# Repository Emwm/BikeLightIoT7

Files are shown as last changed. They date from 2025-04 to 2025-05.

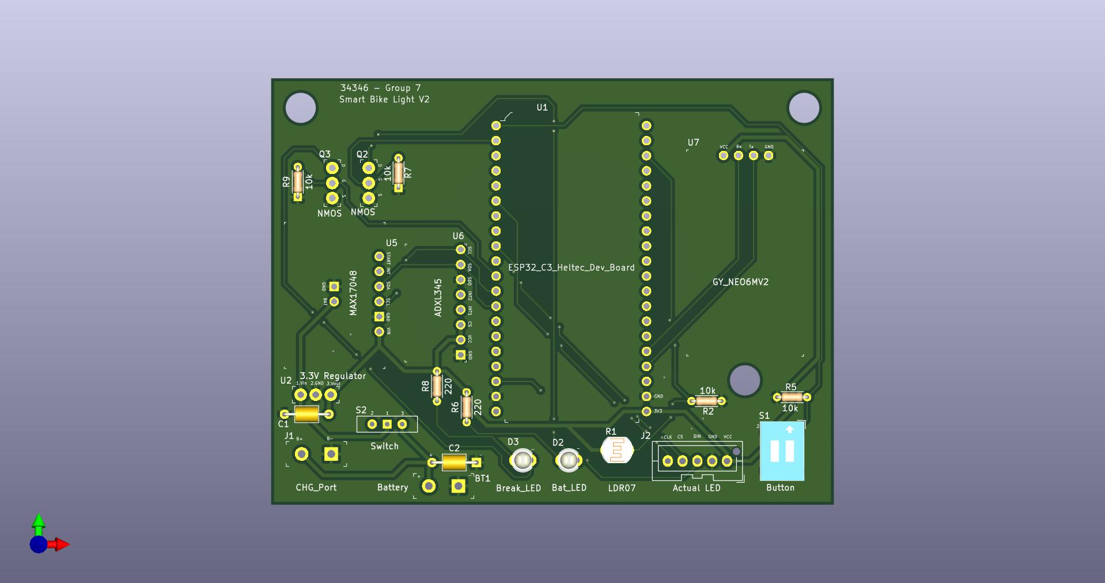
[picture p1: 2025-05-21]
Electronic Hardware/PCB Images/PCB_Rendered_Image.jpg

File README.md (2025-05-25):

# 🚲 ESP32 Smart Bike Tracker

An ESP32-based smart tracking and monitoring system for bicycles, combining GNSS (GPS) tracking, motion detection, power management, battery monitoring, and LoRa communication to create an intelligent, low-power system for bike security and telemetry.

---

## 📚 Table of Contents

- [Features](#-features)
- [Getting Started](#-getting-started)
- [Power Modes](#-power-modes)
- [GNSS (GPS) Handler](#-gnss-gps-handler)
- [Motion Detector](#-motion-detector)
- [Light Control](#-light-control)
- [LoRa Communication](#-lora-communication)
- [Battery Monitoring](#-battery-monitoring)
- [Inactivity Handling](#-inactivity-handling)
- [Main Loop Overview](#-main-loop-overview)
- [Modules Summary](#-modules-summary)
- [Contributing](#-contributing)
- [License](#-license)

---

## 📦 Features

- Real-time GPS tracking  
- LoRa communication to send bike data remotely  
- Motion detection using an accelerometer  
- Battery monitoring via MAX17048 fuel gauge  
- Smart power management with 3 modes: ACTIVE, PARK, SLEEP  
- Inactivity-based sleep transitions  
- Wake-up on button press or timer  
- Integrated button and light control  

---

## 🛠️ Getting Started

### ✅ Prerequisites

- PlatformIO or Arduino IDE  
- ESP32 board definitions installed  
- Required libraries:  
  - TinyGPS++  
  - Wire  
  - SPI  

### 🚀 Flashing the Firmware

```bash
git clone https://github.com/youruser/esp32-smart-bike-tracker.git
cd esp32-smart-bike-tracker
# Open with Arduino IDE or PlatformIO and upload to your ESP32
```

---

## 🔘 Button Handler

Manages button input from GPIO 33, used to:
- Wake up the system
- Trigger GPS updates
- Toggle power modes

### ⚙️ Configuration

| Constant | Description |
|---|---|
| `BUTTON_PIN_1` | GPIO pin for Button 1 (GPIO33) |

```cpp
#define BUTTON_PIN_1 33
```

### 📦 Variables

```cpp
extern volatile bool button1Pressed;
extern unsigned long lastActivityTime;
```

### 📋 API

| Function | Description |
|---|---|
| `setupButtons()` | Initializes GPIOs as `INPUT_PULLDOWN` |
| `checkButtonPresses()` | Resets flags, updates `lastActivityTime` |

---

## 🧠 Power Modes

System behavior varies by mode:

### 🟢 ACTIVE Mode
- Full GPS + LoRa operation
- Motion detection and lighting enabled
- Auto-exit on inactivity

### 🟡 PARK Mode
- Enters light sleep
- Periodic wake via RTC or button
- Ideal for short-term stationary periods

### 🔴 SLEEP Mode
- Enters deep sleep for max power saving
- Wake on button press only
- Best for long inactivity

---

## 🛰 GNSS (GPS) Handler

Handles GPS data using the TinyGPS++ library. Sends the location everytime the mode of the system changes.

### 📋 API

| Method | Description |
|---|---|
| `begin()` | Initializes GPS module |
| `update()` | Feeds serial data to TinyGPS++ |
| `isConnected()` | Checks for GPS fix (≥4 satellites) |
| `checkLocation()` | Returns `GPSPosition` with lat/lon |

### 📍 Example

This flag is used to update the location and send it.

```cpp
if (sendLocationFlag) {
    GPSPosition pos = gnss.checkLocation();
    // Use pos.latitude, pos.longitude
}
```

---

## 🕹️ Motion Detector

Detects bike movement using a 3-axis accelerometer (e.g. ADXL345).

### 📋 API

| Method | Description |
|---|---|
| `isMoving()` | Returns `true` if movement detected |
| `begin()` | Initializes the sensor |
| `MotionDetector(...)` | Constructor with I2C address and threshold |

```cpp
MotionDetector motion(0x53); // ADXL345 default I2C address
```

---

## 💡 Light Control

Uses an LDR + MAX7219 LED matrix to control lights.

### ⚙️ Configuration

| Item | Pin |
|---|---|
| `LDR_PIN` | Analog Input |
| `LED_LOW_BAT` | Digital Output |
| `DIN` | GPIO 14 |
| `CLK` | GPIO 13 |
| `CS` | GPIO 12 |

### 📋 API

| Function | Description |
|---|---|
| `setupLight()` | Initializes LED matrix |
| `controlLight()` | Enables/disables display based on LDR |
| `turnLightoff()` | Manually disables display |
| `manageBatteryWarning(float)`| Activates LED when battery < 25% |

---

## 📡 LoRaWAN Communication

Handles uplink/downlink communication via RN2483 LoRa module using OTAA.

### 🔧 ESP32 to RN2483 Wiring

| Function | ESP32 Pin |
|---|---|
| TX → RN  | GPIO 19 |
| RX ← RN  | GPIO 18 |
| RESET | GPIO 23 |

### 📋 API

| Function | Description |
|---|---|
| `init_lora()` | Initializes LoRaWAN + joins TTN |
| `send_lora(devMode, battery, lon, lat)` | Sends telemetry as CSV string |
| `recieve_lora()` | Reads JSON downlink and parses value|

### 📤 Uplink Format (CSV)

```text
1,3.85,12.34,56.78
```

### 📥 Downlink Format

TTN → JSON string in HEX:

```json
{"value": 2}
```

TTN Payload: `7b2276616c7565223a20327d`

Parsed into `int value = 2`.

---

## 🔋 Battery Monitoring

Powered by the MAX17048 fuel gauge.

```cpp
batterypercentage = battery.percent();
```

Low battery warning is triggered by:

```cpp
manageBatteryWarning(batterypercentage);
```

---

## ⏱️ Inactivity & Mode Handling

Automatically switches to `PARK` mode if idle for 60 seconds:

```cpp
if (millis() - lastActivityTime > 60000) {
    // Switch to PARK
}
```

Button interrupt handler toggles modes:

```cpp
void IRAM_ATTR handleInterrupt1();
```

Transitions:
- `ACTIVE → PARK`
- `PARK → SLEEP`

---

## 🔁 Main Loop Structure

```cpp
switch (getCurrentMode()) {
    case ACTIVE:
        // Motion + LoRa
        break;
    case PARK:
        // Light sleep
        break;
    case SLEEP:
        // Deep sleep
        break;
}
```

---

## 🛠 Modules Summary

| Module | Description |
| --- | --- |
| powerModes | Manages sleep states and wake sources  |
| GNSSHandler | Handles GPS via GNSS |
| MotionDetector | Reads accelerometer to detect movement |
| ESP32\_lora | Sends and receives data via LoRa |
| MAX17048 | Monitors battery charge level |
| buttonHandler  | Detects button presses |
| lightControl | Manages LED or light control |

## Authors

Group 7 in the DTU course 34346 Networking technologies and application development for IoT

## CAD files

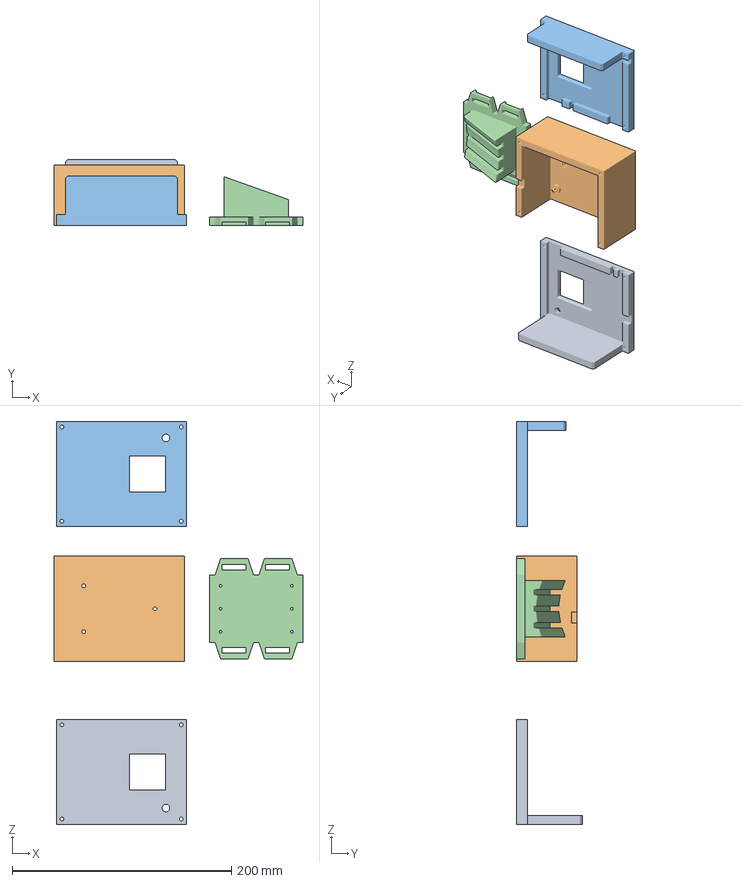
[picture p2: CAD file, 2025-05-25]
CAD Files/BikeLightCase full.3mf
227.0 x 60.0 x 368.0 mm

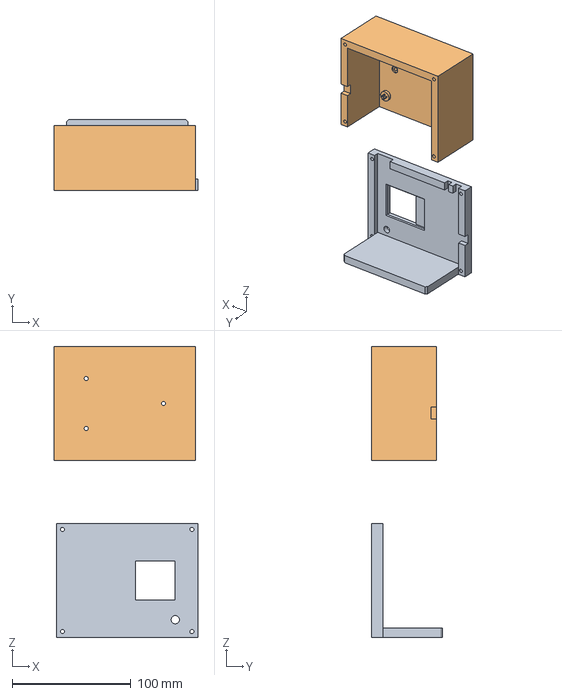
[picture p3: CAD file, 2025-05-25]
CAD Files/BikeLightCase v6.3mf
121.0 x 60.0 x 245.0 mm

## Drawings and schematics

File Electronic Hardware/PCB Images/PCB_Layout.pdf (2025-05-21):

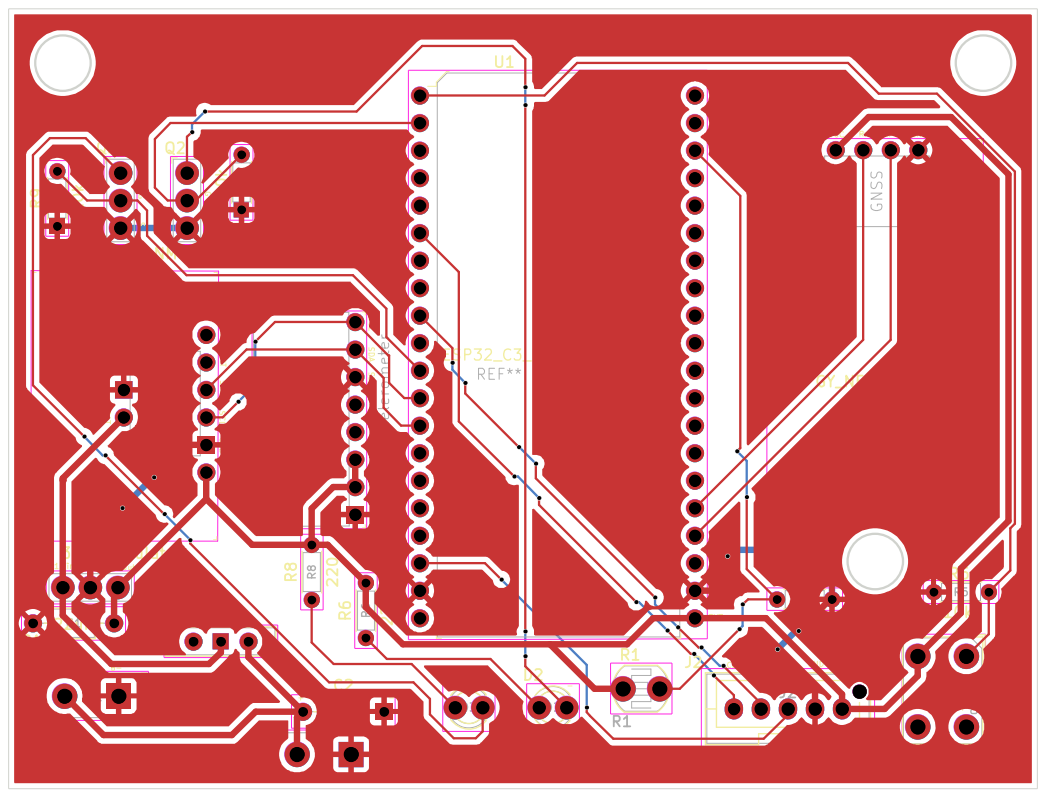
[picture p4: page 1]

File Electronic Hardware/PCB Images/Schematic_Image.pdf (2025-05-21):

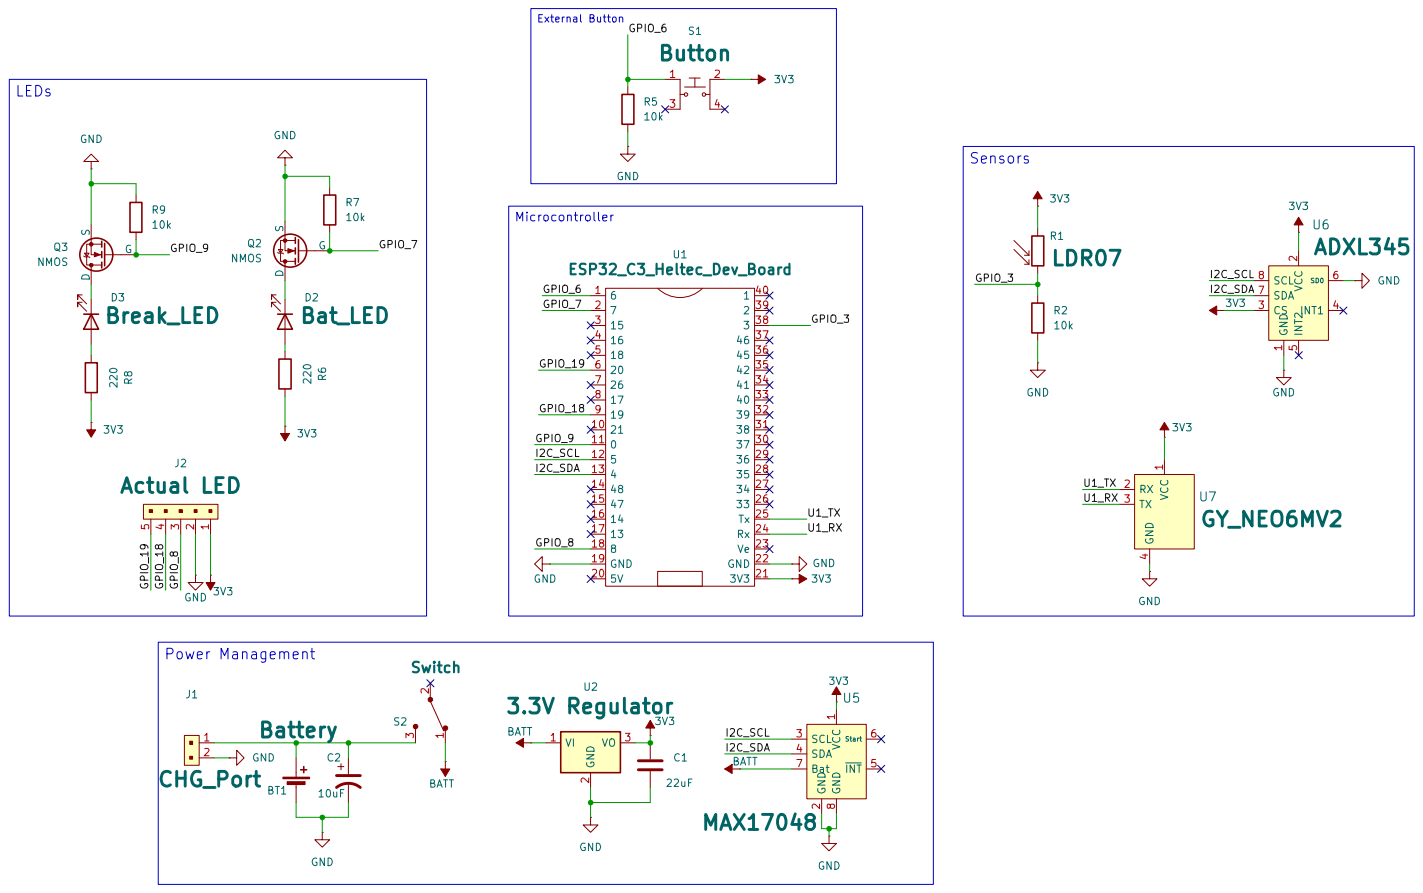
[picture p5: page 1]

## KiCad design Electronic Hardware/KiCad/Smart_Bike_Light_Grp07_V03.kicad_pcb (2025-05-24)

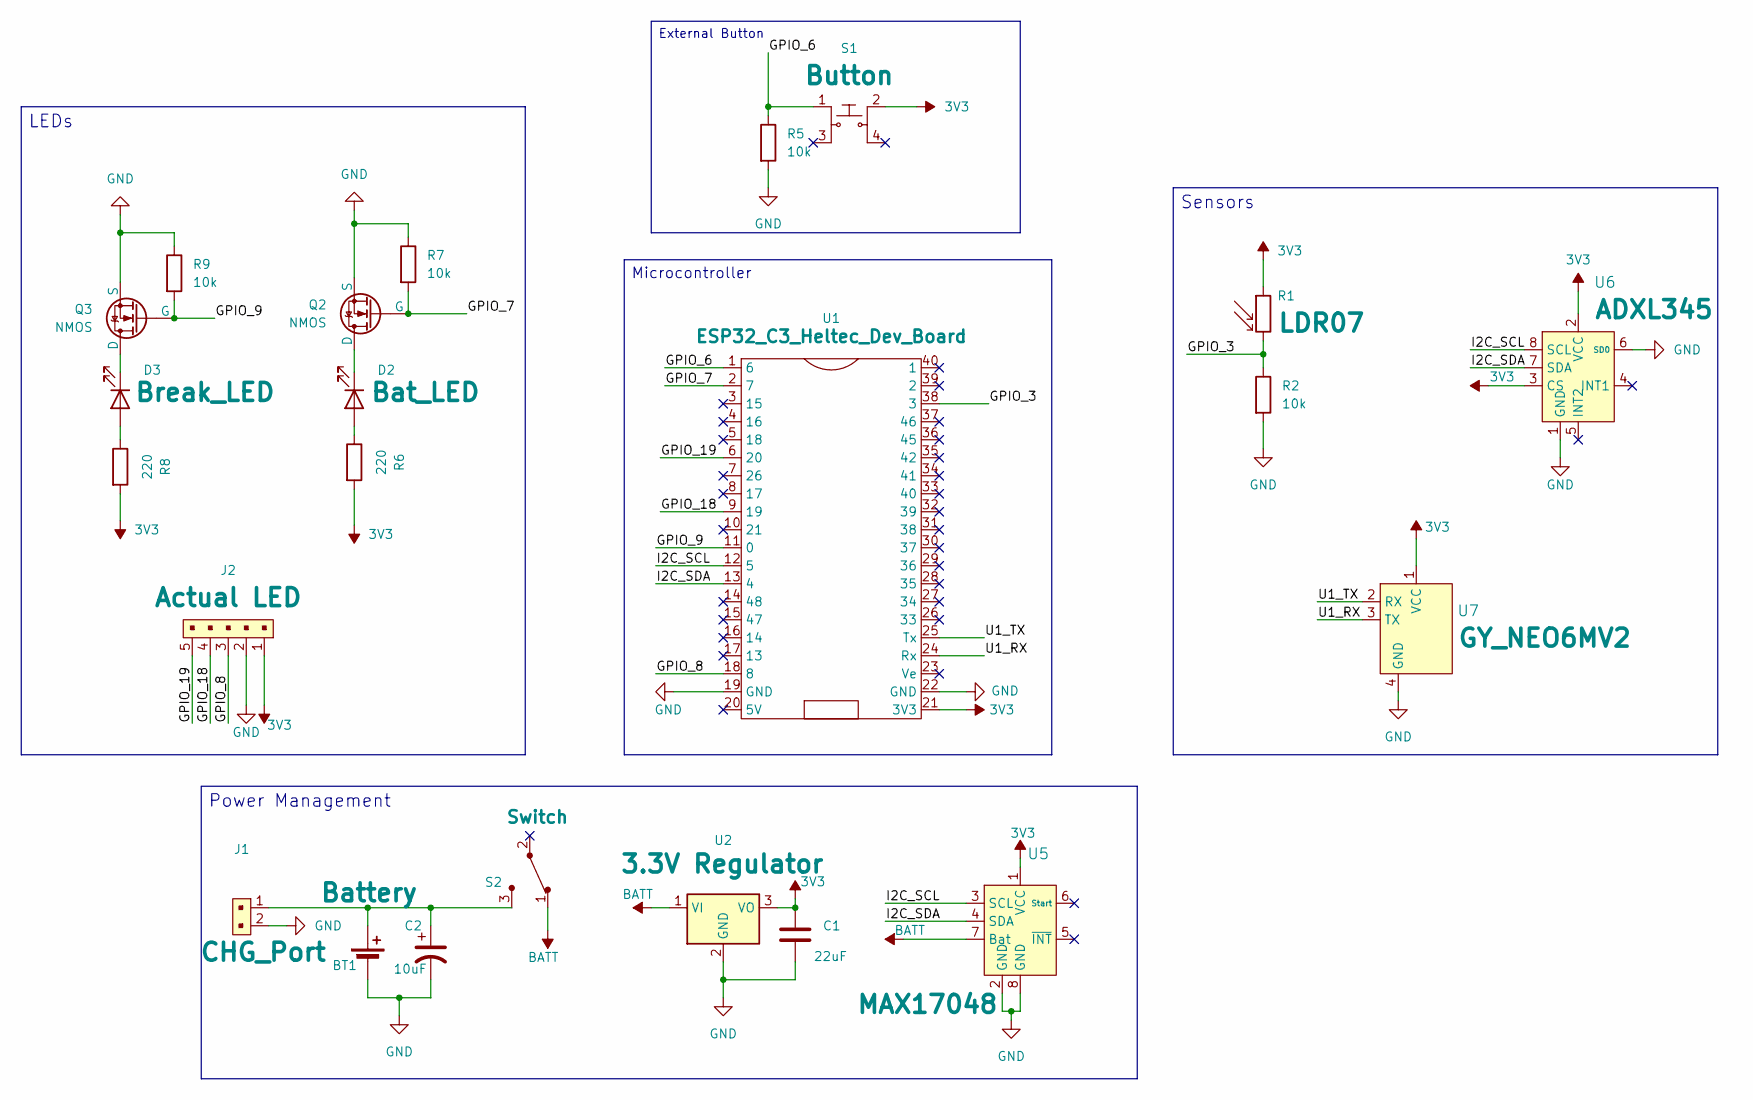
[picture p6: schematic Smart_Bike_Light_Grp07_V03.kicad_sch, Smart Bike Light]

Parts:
BT1: Battery; Terminal_Block_D1.3mm_P5mm
C1: 22uF; C_Axial_L3.8mm_D2.6mm_P7.50mm_Horizontal
C2: 10uF; C_Axial_L3.8mm_D2.6mm_P7.50mm_Horizontal
D2: Bat_LED; LED_D3.0mm_Clear
D3: Break_LED; LED_D3.0mm_Clear
J1: CHG_Port; Terminal_Block_D1.3mm_P5mm; MPN 640456-2; Digi-Key_PN A1921-ND
J2: Actual LED; JST_XA_B05B-XASK-1-A_1x05_P2.50mm_Vertical; MPN B5B-XH-A(LF)(SN); Digi-Key_PN 455-2270-ND
Q2, Q3: NMOS; PinHeader_1x3_P2.54_Drill1.1mm
R1: LDR07; R_LDR_5.1x4.3mm_P3.4mm_Vertical
R2, R5, R7, R9: 10k; R_Axial_DIN0204_L3.6mm_D1.6mm_P5.08mm_Horizontal
R6, R8: 220; R_Axial_DIN0204_L3.6mm_D1.6mm_P5.08mm_Horizontal
S1: Button; SW_DIP_SPSTx02_Slide_9.78x7.26mm_W7.62mm_P2.54mm; MPN KS-01Q-01; Digi-Key_PN EG4791-ND
S2: Switch; SW_Slide-03_Wuerth-WS-SLTV_10x2.5x6.4_P2.54mm; MPN EG1218; Digi-Key_PN EG1903-ND
U1: ESP32_C3_Heltec_Dev_Board; DIP-40_W25.4mm
U2: 3.3V Regulator; PinHeader_1x3_P2.54_Drill1.1mm
U5: MAX17048; DIP-8_W7.62mm; MPN MAX44009EDT+T; Digi-Key_PN MAX44009EDT+TCT-ND
U6: ADXL345; DIP-8_W7.62mm; MPN MAX44009EDT+T; Digi-Key_PN MAX44009EDT+TCT-ND
U7: GY_NEO6MV2; DIP-8_W7.62mm; MPN MAX44009EDT+T; Digi-Key_PN MAX44009EDT+TCT-ND

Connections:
-3V3: C1.1, J2.1, R1.1, R6.2, R8.2, S1.2, U1.21 (3V3), U2.3 (VO), U5.1 (VCC), U6.2 (VCC), U6.3 (CS), U7.1 (VCC)
-BATT: S2.1, U2.1 (VI), U5.7 (Bat)
/GPIO_3: R1.2, R2.1, U1.38 (3)
/GPIO_6: R5.1, S1.1, U1.1 (6)
/GPIO_7: Q2.2 (G), R7.2, U1.2 (7)
/GPIO_8: J2.3, U1.18 (8)
/GPIO_9: Q3.2 (G), R9.2, U1.11 (0)
/GPIO_18: J2.4, U1.9 (19)
/GPIO_19: J2.5, U1.6 (20)
/I2C_SCL: U1.12 (5), U5.3 (SCL), U6.8 (SCL)
/I2C_SDA: U1.13 (4), U5.4 (SDA), U6.7 (SDA)
/U1_RX: U1.24 (Rx), U7.3 (TX)
/U1_TX: U1.25 (Tx), U7.2 (RX)
GND: BT1.2 (-), C1.2, C2.2, J1.2, J2.2, Q2.3 (S), Q3.3 (S), R2.2, R5.2, R7.1, R9.1, U1.19 (GND), U1.22 (GND), U2.2 (GND), U5.2 (GND), U5.8 (GND), U6.1 (GND), U6.6 (SD0), U7.4 (GND)
unnamed: BT1.1 (+), C2.1, J1.1, S2.3
unnamed: D2.2 (A), R6.1
unnamed: D2.1 (K), Q2.1 (D)
unnamed: D3.2 (A), R8.1
unnamed: D3.1 (K), Q3.1 (D)

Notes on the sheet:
Power Management
External Button
Microcontroller
LEDs
Sensors

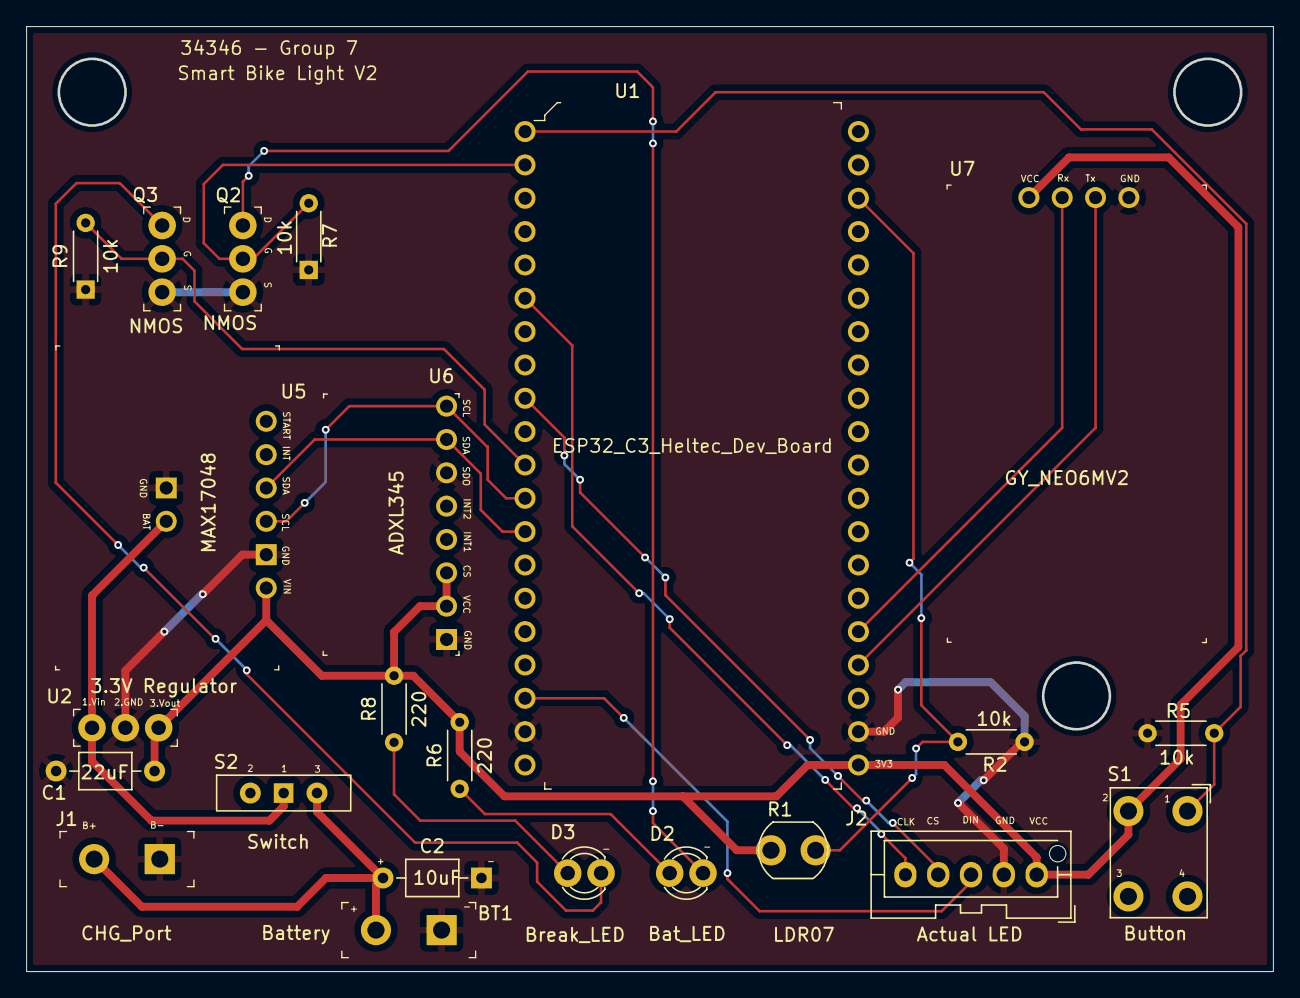
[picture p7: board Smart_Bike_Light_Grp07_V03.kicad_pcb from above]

Board: 2 copper layers, 95.0 x 72.0 mm, 23 parts (0 on the bottom side), 19 nets.

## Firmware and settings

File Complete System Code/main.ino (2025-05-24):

#include "powerModes.h"
#include "buttonHandler.h"
#include "lightControl.h"
#include "GNSSHandler.h"
#include "MotionDetector.h"
#include "ESP32_lora.h"
#include "MAX17048.h"

// Define the pins for GNSS module communication
#define GNSS_RX 16
#define GNSS_TX 17
#define DEVICE_ADDR 0x53  // Address of the motion sensor (accelerometer)

// Create instances of the modules for GNSS, motion detection, and GPS position
GNSSHandler gnss(Serial1, GNSS_RX, GNSS_TX);  // Create an object for GNSS communication
MotionDetector detector(DEVICE_ADDR);        // Create an object for the motion detector (accelerometer)
MAX17048 battery;
GPSPosition pos;  // Variable to store the current GPS position
float batterypercentage;


// ---- Setup function: Initializes all components of the system ----
void setup() {
    Serial.begin(115200);       // Start serial communication at 115200 baud rate for debugging

    // Initialize system components
    init_lora();
    setupLight();      // Setup light control and initialize related components
    setupButtons();    // Setup button pins and interrupts
    setupPowerModes(); // Setup power modes and configure interrupts
    gnss.begin();      // Initialize the GNSS (GPS) module
    Wire.begin();  // Initialize I2C
    battery.attatch(Wire);  // Attach MAX17048 to the I2C bus
    detector.begin();  // Initialize the motion detector module (accelerometer)
    

    // Print a ready message once all components are initialized
    Serial.println("ESP32 Ready!");
}

// ---- Main Loop function: Runs continuously to manage system state and handle events ----
void loop() {

    
    // Call button checking to handle button presses and reset inactivity timers
    checkButtonPresses();

    // Automatically enter sleep mode after 30 seconds of inactivity
    checkInactivity();

    // Checking the battery status
    batterypercentage = battery.percent();
    Serial.println(batterypercentage);


    // If the flag to send location is set, update location and print GPS coordinates
    if (sendLocationFlag) {
        sendLocationFlag = false;  // Clear the flag once location data is being processed

        // Get the current GPS position
        pos = gnss.checkLocation();

        // Print the GPS coordinates (latitude and longitude) to the serial monitor for debugging
        Serial.print("Latitude: ");
        Serial.print(pos.latitude, 6);
        Serial.print(", Longitude: ");
        Serial.println(pos.longitude, 6);

        // Add your sending logic here (e.g., send location via LoRa, HTTP, etc.)
    }

    

    // Handle different power modes based on the current mode (ACTIVE, PARK, SLEEP)
    switch (getCurrentMode()) {
        case ACTIVE:
            gnss.update();  // Update GNSS module with new GPS data
            manageBatteryWarning(batterypercentage);
            // Check if the bike is moving by detecting motion via the accelerometer
            if(detector.isMoving() == true) {
                lastActivityTime = millis();  // Reset the inactivity timer if movement is detected
            }
            Serial.println("Check movement");  // Debugging message
            activeMode();  // Perform actions related to active mode (e.g., light control)
            send_lora(getCurrentMode(),batterypercentage,pos.longitude,pos.latitude);
            setCurrentMode(recieve_lora());
            break;

        case PARK:
            lastActivityTime = millis();  // Reset the inactivity timer if movement is detected
            parkMode();  // Perform actions related to park mode (e.g., light sleep)
            send_lora(getCurrentMode(),batterypercentage,pos.longitude,pos.latitude);
            setCurrentMode(recieve_lora());
            break;

        case SLEEP:
            send_lora(getCurrentMode(),batterypercentage,pos.longitude,pos.latitude);
            setCurrentMode(recieve_lora());
            sleepMode();  // Perform actions related to sleep mode (e.g., deep sleep)
            break;
    }
}

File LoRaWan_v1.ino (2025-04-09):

/* Heltec Automation LoRaWAN communication example
 *
 * Function:
 * 1. Upload node data to the server using the standard LoRaWAN protocol.
 *  
 * Description:
 * 1. Communicate using LoRaWAN protocol.
 * 
 * HelTec AutoMation, Chengdu, China
 * 成都惠利特自动化科技有限公司
 * www.heltec.org
 *
 * 
 */

// use wireless mini shell board name so lora options are in the tools

#include "LoRaWan_APP.h"

// we can use Cibicom to generate all parameters
/* OTAA (over the air activation) para*/
// cibicom generated dev EUI = BE-7A-00-00-00-00-02-8A (if you go to the devices tab you can see the device EUI in a good format)
// I also tried device generated devEUI = AD AE 3D 98 00 00 24 DA
uint8_t devEui[] = { 0xAD, 0xAE, 0x3D, 0x98, 0x00, 0x00, 0x24, 0xDA };
// app EUI = join EUI = BE7A000000001465
uint8_t appEui[] = { 0xBE, 0x7A, 0x00, 0x00, 0x00, 0x00, 0x14, 0x65 };
// in lorawan parameters tab = C0 F7 0B 05 FF 25 DB 7A 8D FB 25 FF 12 44 13 62
uint8_t appKey[] = { 0xC0, 0xF7, 0x0B, 0x05, 0xFF, 0x25, 0xDB, 0x7A, 0x8D, 0xFB, 0x25, 0xFF, 0x12, 0x44, 0x13, 0x62 };

//we do not need these
/* ABP para*/
uint8_t nwkSKey[] = { 0xBB, 0x8F, 0x62, 0xB4, 0x5E, 0x4C, 0x66, 0xEF, 0x47, 0x51, 0x6F, 0x1C, 0xD9, 0x7B, 0x89, 0xDD };
uint8_t appSKey[] = { 0x91, 0x1C, 0xB0, 0x92, 0xE1, 0xD0, 0x9A, 0x0A, 0x55, 0xDF, 0x3B, 0x08, 0xF3, 0xCC, 0x91, 0x5C };
uint32_t devAddr =  ( uint32_t )0x01F768DD;

/*LoraWan channelsmask, default channels 0-7*/ 
// this is enabling channels 0 to 7 using a bitmask array,  eu868 uses channels 0-2 usually
uint16_t userChannelsMask[6]={ 0x00FF,0x0000,0x0000,0x0000,0x0000,0x0000 };

/*LoraWan region, select in arduino IDE tools*/
LoRaMacRegion_t loraWanRegion = ACTIVE_REGION;

/*
LoraWan Class, Class A and Class C are supported
We want to use Class A as it has lowest battery consumption
The device will oly listen after sneding data
*/
DeviceClass_t  loraWanClass = CLASS_A; 

/*
the application data transmission duty cycle.  value in [ms].
the transmission interval will be 15s
*/
uint32_t appTxDutyCycle = 15000;

/*OTAA or ABP*/
bool overTheAirActivation = true;

/*ADR (adaptive data rate) enable (which is used for power efficiency)*/
bool loraWanAdr = true;

/* Indicates if the node is sending confirmed or unconfirmed messages */
bool isTxConfirmed = true;

/* 
Application port
this port routes data to the correct application on the network server
enables multiple application to use the same lorawan connection
allows devices to send different types of data on different ports
Port 0 is for Lorawan MAC commands
Port 1-223 is for application-specific data
*/
uint8_t appPort = 2;
/*!
* Number of trials to transmit the frame, if the LoRaMAC layer did not
* receive an acknowledgment. The MAC performs a datarate adaptation,
* according to the LoRaWAN Specification V1.0.2, chapter 18.4, according
* to the following table:
*
* Transmission nb | Data Rate
* ----------------|-----------
* 1 (first)       | DR
* 2               | DR
* 3               | max(DR-1,0)
* 4               | max(DR-1,0)
* 5               | max(DR-2,0)
* 6               | max(DR-2,0)
* 7               | max(DR-3,0)
* 8               | max(DR-3,0)
*
* Note, that if NbTrials is set to 1 or 2, the MAC will not decrease
* the datarate, in case the LoRaMAC layer did not receive an acknowledgment
*/
uint8_t confirmedNbTrials = 4; // how many times it tries again to receive the acknowledgment


/* Prepares the payload of the frame */
static void prepareTxFrame( uint8_t port )
{
  /*appData size is LORAWAN_APP_DATA_MAX_SIZE which is defined in "commissioning.h".
  *appDataSize max value is LORAWAN_APP_DATA_MAX_SIZE.
  *if enabled AT, don't modify LORAWAN_APP_DATA_MAX_SIZE, it may cause system hanging or failure.
  *if disabled AT, LORAWAN_APP_DATA_MAX_SIZE can be modified, the max value is reference to lorawan region and SF.
  *for example, if use REGION_CN470, 
  *the max value for different DR can be found in MaxPayloadOfDatarateCN470 refer to DataratesCN470 and BandwidthsCN470 in "RegionCN470.h".
  */
    appDataSize = 4;
    appData[0] = 0x00;
    appData[1] = 0x01;
    appData[2] = 0x02;
    appData[3] = 0x03;
}

//if true, next uplink will add MOTE_MAC_DEVICE_TIME_REQ 

void setup() {
  Serial.begin(115200);
  Mcu.begin(HELTEC_BOARD,SLOW_CLK_TPYE); //initialize lorawan board
  //Serial.println("initialized lorawan board");
}

void loop()
{
  switch( deviceState )
  {
    //initializes the lorawan settings
    case DEVICE_STATE_INIT: 
    {
#if(LORAWAN_DEVEUI_AUTO) // this can be set in the tools tab of arduino IDE
      LoRaWAN.generateDeveuiByChipID();
#endif
      LoRaWAN.init(loraWanClass,loraWanRegion); //set the region in the tools tab of arduino IDE
      //both set join DR and DR when ADR off 
      LoRaWAN.setDefaultDR(3);
      //Serial.println("initialized lorawan settings");
      break;
    }
    //joins the lorawan network
    case DEVICE_STATE_JOIN:
    {
      //Serial.println("tyring to join lorawan network");
      LoRaWAN.join();
      break;
    }
    //prepares and sends data
    case DEVICE_STATE_SEND:
    {
      //Serial.println("preparing to send data");
      prepareTxFrame( appPort );
      LoRaWAN.send();
      deviceState = DEVICE_STATE_CYCLE;
      break;
    }
    // waits before next transmission (waits for a randomized duty cycle delay and moves to sleep mode)
    case DEVICE_STATE_CYCLE:
    {
      //Serial.println("waiting in duty cycle delay");
      // Schedule next packet transmission
      // the randomized duty cycle delay helps prevent collisions with other lorawan devices
      txDutyCycleTime = appTxDutyCycle + randr( -APP_TX_DUTYCYCLE_RND, APP_TX_DUTYCYCLE_RND );
      LoRaWAN.cycle(txDutyCycleTime);
      deviceState = DEVICE_STATE_SLEEP;
      break;
    }
    //enters sleep mode
    case DEVICE_STATE_SLEEP:
    {
      //Serial.println("entering sleep mode");
      LoRaWAN.sleep(loraWanClass);
      break;
    }
    // if the stat is undefined, reinitialize the device
    default:
    {
      //Serial.println("undefined state, reinitializing the device");
      deviceState = DEVICE_STATE_INIT;
      break;
    }
  }
}

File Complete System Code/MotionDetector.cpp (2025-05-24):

#include "MotionDetector.h"
#include <Wire.h>

// Constructor: Initializes the MotionDetector object
MotionDetector::MotionDetector(uint8_t deviceAddress, int threshold)
  : device(deviceAddress), threshold(threshold), prevX(0), prevY(0), prevZ(0) {}

// Initializes the I2C communication and sets the sensor to measurement mode
void MotionDetector::begin() {
  writeTo(0x2D, 0x08);  // Set the device to measurement mode (specific to your sensor)
}

// Checks if the device is moving by comparing the current accelerometer data with the previous data
bool MotionDetector::isMoving() {
  readFrom(0x32, toRead, buff); // Read the accelerometer data from the sensor

  // Extract X, Y, and Z axis data from the buffer
  int x = (((int)buff[1]) << 8) | buff[0];  // Combine the high and low bytes for X axis data
  int y = (((int)buff[3]) << 8) | buff[2];  // Combine the high and low bytes for Y axis data
  int z = (((int)buff[5]) << 8) | buff[4];  // Combine the high and low bytes for Z axis data

  // Print the X, Y, and Z values for debugging
  Serial.print("X="); Serial.print(x);
  Serial.print(" Y="); Serial.print(y);
  Serial.print(" Z="); Serial.println(z);

  // Check if the change in X, Y, or Z exceeds the threshold, indicating movement
  bool moved = (abs(x - prevX) > threshold ||
                abs(y - prevY) > threshold ||
                abs(z - prevZ) > threshold);

  // Update previous X, Y, and Z values to the current ones
  prevX = x;
  prevY = y;
  prevZ = z;

  return moved;  // Return true if movement was detected, false otherwise
}

// Writes a byte of data to the sensor at a specific register address
void MotionDetector::writeTo(byte address, byte val) {
  Wire.beginTransmission(device); // Start communication with the device
  Wire.write(address);             // Send the register address
  Wire.write(val);                 // Send the value to write
  Wire.endTransmission();          // End the transmission to the device
}

// Reads a specified number of bytes from the sensor at a given register address
void MotionDetector::readFrom(byte address, int num, byte* buff) {
  Wire.beginTransmission(device);  // Start communication with the device
  Wire.write(address);             // Send the register address to start reading from
  Wire.endTransmission(false);     // Use repeated start condition (important for I2C)
  
  // Request the specified number of bytes from the device
  Wire.requestFrom(device, num);
  int i = 0;
  // Read the bytes and store them in the buffer
  while (Wire.available() && i < num) {
    buff[i++] = Wire.read();  // Read and store data in the buffer
  }
}

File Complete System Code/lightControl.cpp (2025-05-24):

#include "lightControl.h" // Include the header for light control functionality

// ---- Light Sensitivity Threshold ----
// Below this value (from LDR), the light will turn ON
int threshold = 1500;

MD_MAX72XX mx = MD_MAX72XX(HARDWARE_TYPE, DATA_PIN, CLK_PIN, CS_PIN, MAX_DEVICES);

// ---- FUNCTION: Initialize Light Pin ----
// Sets up the output pin for controlling the light (LED or relay)
void setupLight() {
    pinMode(LED_LOW_BAT, OUTPUT);     // Low battery warning LED
    mx.begin();
    mx.control(MD_MAX72XX::INTENSITY, 5);  // Set brightness (0-15)
    mx.clear();
}

// ---- FUNCTION: Control Light Based on LDR Sensor Reading ----
// Turns light ON if environment is dark (LDR value below threshold), OFF otherwise
void controlLight() {
    int lightLevel = analogRead(LDR_PIN); // Read light intensity from LDR sensor
    Serial.printf("Light Level: %d\n", lightLevel); // Debug print of LDR value

    if (lightLevel < threshold) {
        for (int row = 0; row < 8; row++) {
        mx.setRow(0, row, B11111111);  // Turning LEDs on
    }
        Serial.println("Light ON");        // Log action
    } else {
        mx.clear();
        Serial.println("Light OFF");       // Log action
    }

}

// ---- FUNCTION: Force Light OFF ----
// Ensures the light is turned off regardless of LDR input
void turnLightoff() {
    mx.clear();
    Serial.println("Light OFF");  // Log action
}

// ---- FUNCTION: Manage Low Battery LED Warning ----
// Turns ON the low battery LED if the battery percentage drops below 25%,
// otherwise turns it OFF. This helps save energy by only activating the LED when necessary.
void manageBatteryWarning(float batterypercentage) {
    if (batterypercentage < 25) {
        digitalWrite(LED_LOW_BAT, HIGH);  // Turn ON the low battery LED
    } else {
        digitalWrite(LED_LOW_BAT, LOW);   // Turn OFF the LED if battery is sufficient
    }
}

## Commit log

2025-05-16 ESP32 lorawan
2025-05-21 Fritzing ESP32 Wroom
    [SmartBikeLight.fzz]
2025-05-21 PCB Files Kicad
    [Smart_Bike_Light_Grp07_V03.kicad_pcb, Smart_Bike_Light_Grp07_V03.kicad_sch]
2025-05-21 Schematic Image
2025-05-21 PCB Layout Image
2025-05-21 Rendered Image PCB
2025-05-21 Gerber File
2025-05-21 All FootPrints
2025-05-24 Update powerModes.cpp
    Updated code that it also sends location, if the mode is changed by the frontend
2025-05-24 Electronic Hardware Reorganized
    [SmartBikeLight.fzz, Smart_Bike_Light_Grp07_V03.kicad_pcb, Smart_Bike_Light_Grp07_V03.kicad_sch]
2025-05-25 Cad files
    [BikeLightCase full.3mf, BikeLightCase v6.3mf]
